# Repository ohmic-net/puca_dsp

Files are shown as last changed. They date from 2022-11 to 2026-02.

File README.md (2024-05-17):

# PÚCA DSP

**PÚCA DSP** is an open source, Arduino compatible ESP32 development board for audio and digital signal processing applications. In this repository you will find the hardware design files, and software examples for; 
- Arduino IDE
- VSCode/PlatformIO with Platform Espressif 32 and Framework arduinoespressif32 
- VSCode/PlatformIO with Platform Espressif 32 and Framework espidf
- ESP IDF

# Specifications 

**Processor & Memory**
- Espressif ESP32 Pico D4 Processor
- 32-bit dual core 80MHZ / 160MHZ / 240MHZ
- 4MB SPI Flash with 8MB additional PSRAM or 16MB External SPI Flash 
- Wireless 2.4GHz Wi-Fi -802.11b/g/n
- Bluetooth BLE 4.2
- 3D Antenna

**Audio**
- Wolfson WM8978 Stereo Audio Codec
- Audio Line In on stereo 3.5mm connector
- Audio Headphone / Line Out on stereo 3.5mm connector
- Stereo Aux Line In, Audio Mono Out routed to GPIO Header
- 2 x Knowles SPM0687LR5H-1 MEMS Microphones 
- ESD protection on all audio inputs and outputs
- Support for 8, 11.025, 12, 16, 22.05, 24, 32, 44.1 and 48kHz sample rates
- 1W Speaker Driver, routed to GPIO Header
- DAC SNR 98 dB, THD -84 dB (‘A’ weighted @ 48 kHz)
- ADC SNR 95 dB, THD -84 dB (‘A’ weighted @ 48 kHz)
- Line input impedance: 1 M ohm
- Line output impedance: 33 ohm

**Form Factor and Connectivity**
- Breadboard friendly
- 70mm x 24mm
- 11 x GPIO pins broken out to 2.54mm pitch header, with access to both ESP32 ADC channels, JTAG and capacitive touch pins
- USB 2.0 over USB Type C connector

**Power**
- 3.7/4.2v Lithium Polymer Rechargeable Battery, USB  or external 5V DC power source
- ESP32 and Audio Codec can be placed into low power modes under software control
- Battery voltage level detection
- ESD protection on USB data bus

# Documentation 
PUCA_DSP-PINOUT_V2

# Pin Description
pin_description_repo-2

# Absolute Maximum Ratings 
abs_max_repo_v2

Maximum voltage before clipping on Audio Input, Aux L & Aux R = 3.3V peak-to-peak, AC. Audio input paths are AC coupled. 

Maximum voltage on GPIO pins = 3.3V DC. GPIO pins are not overvoltage protected, for voltages higher than 3.3V use an input protection circuit such as a diode clamp or a level shifter.

# Current Consumption Characteristics 
current_repo

# Battery Voltage Monitoring
Battery voltage monitoring is available by soldering the BT_LVL solder jumper on the PCB top side, which routes the battery voltage to GPIO 14. 

# Physical Dimensions
phys_dimensions_repo

*Height measurement is with pin headers soldered. 

# Open Source Licensing 
certification-mark-IE000006-wide
**PÚCA DSP** is Open Source Hardware Association certified, and can be found on the OSHWA website here; https://certification.oshwa.org/list.html

Hardware design files are released as open source under the CERN v1.2 license. **PÚCA DSP** software examples are released under the MIT license, software examples using Faust DSP also contain additional license information relevant to Faust DSP. Please review these licenses before using these files in your own projects to understand your obligations.

# Video Tutorials
1. Getting started with VS Code and PlatformIO IDE - https://www.youtube.com/watch?v=hKllKXUncVo
2. Configuring the audio codec - https://www.youtube.com/watch?v=Auh9VE7Pjl8

# Need a board?
There are a few available on Tindie - https://www.tindie.com/products/ohmic/puca-dsp/

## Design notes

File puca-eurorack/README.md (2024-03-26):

# PÚCA Eurorack Module

This directory includes binary files (`firmware.bin`) for the Eurorack module. 

## Updating the firmware; 

On boot the module creates a WiFi soft access point with the network name "PÚCA DSP". If you open a browser window (Chrome, Firefox) and go to;`http://puca_dsp.local` you will find an html page with a firmware update function;

OTA_update

Select the new firmware.bin file to load from your local machine and click "Update". After the new firmware has been uploaded, the module will reset and the new firmware will boot. At this point the network connection will be lost, and then on reboot a new WiFi soft access point will be created. 

Note that you don't need to upload the partitions.bin or spiffs.bin files if using the web browser for over the air updates, unless you have changed these, they are included in each folder in case you are using esptool.py or the Espressif Flash Download Tool instead of the module OTA functionality.

## User Interface
User interface parameters and DSP parameters for each firmware are outlined below. On the module; 
- CV1 is the left CV input jack, CV2 is the middle CV input jack and/or the top potentiometer, and CV3 is the right CV input jack and/or the bottom potentiometer. 
- TRIG1 is the top trigger input and TRIG2 is the bottom trigger input. 
- TOUCH is the capacitive touch sensor activated by touching the PÚCA's paw. 

The `hardware_test_arduino` folder includes Arduino sketches for checking that the hardware functionality is working correctly.

## Current firmwares; 

- **SNES_Verb** - emulation of a SNES type reverb with a short delay line. CV2 is delay time, and CV3 is feedback. 
- **Oscillator** - a wavetable oscillator with 12 single cycle, band limited waveforms. CV1 is the 1V/Octave input, CV2 is the oscillator root frequency, and CV3 is linear FM. A TOUCH input or a trigger signal on TRIG1 will switch the waveform.
- **Chorus** - stereo chorus effect. CV2 is depth, and CV3 is phase difference. 

#### Notes on the oscillator frequency range; 

The 1V/Octave input has a range of 7 octaves, due to the non-linearity of the ESP32's ADC inputs the pitch tracking is accurate over 4 octaves and the lowest and highest octaves do not track accurately, as can be seen from the below graph whereby the linear response region is between 2V and 6V. The pitch resolution is 34.375mV per semitone or 0.34375 mV per cent. 

Puca_VOCT_input

The Oscillator root frequency range is from midi note A0 (27.50Hz) to A3 (220Hz), used in combination with the 1V/Octave input in practice this gives a musically usable range of around 4 to 6 octaves from A0 without note drift. 

The FM input allows for linear frequency modulation up to maximum frequency range of 1 midi note.

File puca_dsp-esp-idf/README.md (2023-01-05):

# ESP-IDF v5.0 Example

The examples in this directory build against [Espressif ESP-IDF development Framework v5.0](https://docs.espressif.com/projects/esp-idf/en/v5.0/esp32/get-started/index.html). Follow the documentation on the linked page to install v5.0 to build these examples.

If you are hoping to build against ESP-IDF v4.0, refer to the `puca_dsp-platformio-esp-idf` [examples](https://github.com/ohmic-net/puca_dsp/tree/main/puca_dsp-platformio-esp-idf).

To build, once the ESP-IDF toolchain is initialised (usually `get_idf`), run:
```
idf.py build
```
In this example's directory (`puca_dsp/puca_dsp-esp-idf`).

Two example I2S functions are provided in `main.cpp`:
- `passthrough()` sends all I2S data received from the ADC to the DAC, so that the PÚCA DSP is transparent.
- `sine_wave()` generates a 200Hz sine wave at the output.

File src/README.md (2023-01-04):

This directory is intended for project specific (private) libraries, and can be expanded over time to include 
different signal processing classes, networking and OTA functionality and user interface functionality.

Example directory structure; 

- Audio - contains audio codec driver (WM8978) and functions related to I2S audio configuration
- Control - contains functions related to control parameters (potentiometers, buttons, trigger inputs)

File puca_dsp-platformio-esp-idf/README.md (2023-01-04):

This directory contains software examples for; 
- VSCode/PlatformIO with Platform Espressif 32 and Framework esp-idf

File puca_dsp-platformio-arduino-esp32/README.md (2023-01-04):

This directory contains software examples for; 
- VSCode/PlatformIO with Platform Espressif 32 and Framework arduinoespressif32

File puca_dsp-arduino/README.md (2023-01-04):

This directory contains software examples for; 
- Arduino IDE

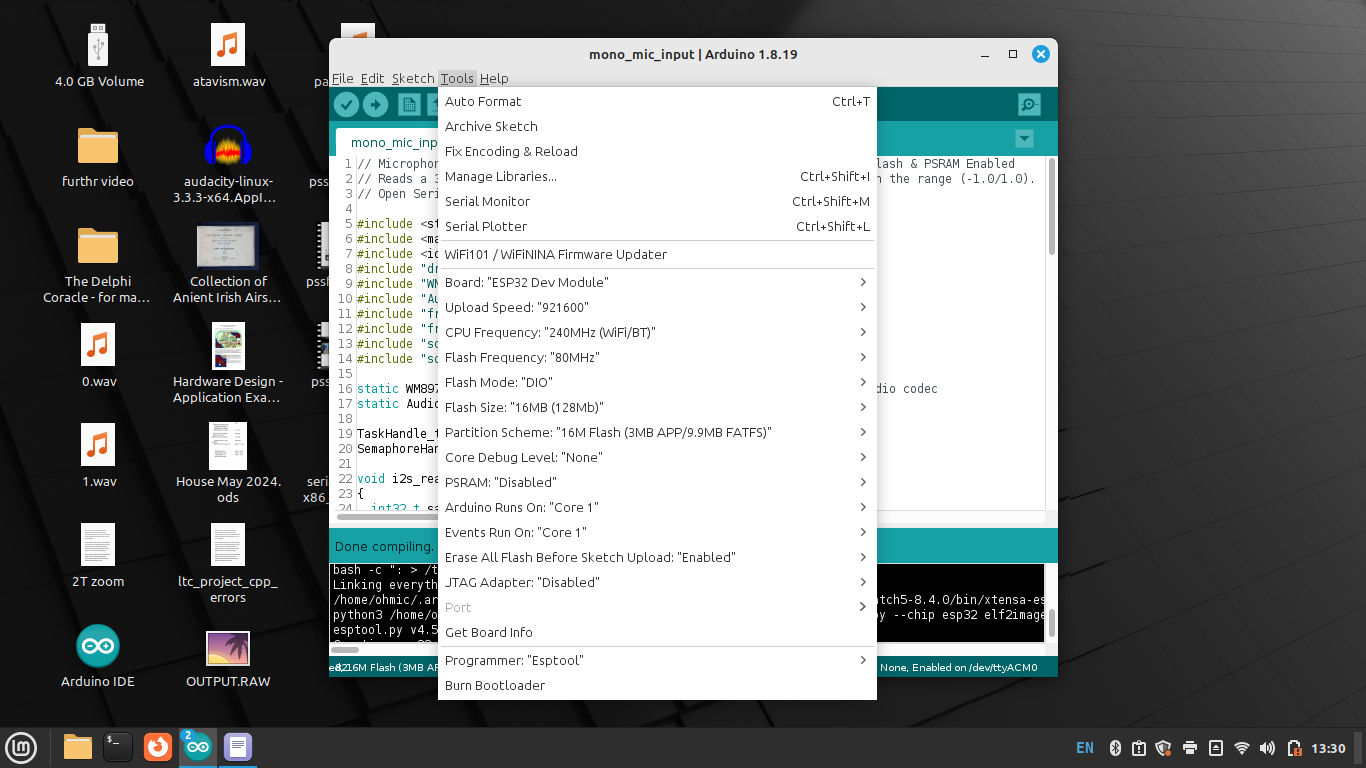
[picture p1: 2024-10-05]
puca_dsp-arduino/strawberry edition/Arduino_IDE_settings.png

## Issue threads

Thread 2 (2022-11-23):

https and mp3

nebulos13, 2022-11-23:
hello i try webradio in arduino -internet-radio.ino with this list radio:

https://radiobonheur.ice.infomaniak.ch/radiobonheur-128-1.mp3
http://direct.franceinter.fr/live/franceinter-midfi.mp3
https://ais-live.cloud-services.paris:8443/rfm.mp3
http://cdn.nrjaudio.fm/audio1/fr/30401/mp3_128.mp3?origine=fluxradios
http://radioclassique.ice.infomaniak.ch/radioclassique-high.mp3
http://radio8.pro-fhi.net:9005/atlantis320
http://tachyon.shoutca.st:8084/live
http://stream.levillage.org/canalb?1362308951917.mp3

but nothing playing just http://direct.franceinter.fr/live/franceinter-midfi.mp3
how to have mp3 extention and https
thanks to your answer

nebulos13, 2022-11-23:
now my problem is the button to change mp3 flux

g0fcu, 2022-11-24:
There is a difference in code between the Arduino IDE and VSCode IDE versions. The Arduino version has the set up of the interrupt which triggers when the button is pressed. However, for me this version continuously reboots. The VSCode has these lines (123-127) commented out so the station which plays is that which station_select is set to in Setup(). Uncommenting these lines causes the same constant reboots as in the Arduino version.

nebulos13, 2022-11-24:
Thanks to your answer. Have you solution to use button to change radio station ?

g0fcu, 2022-11-25:
I just cloned the git repository again and my previous comment about code differences is wrong (I must have made the change). The button and the interrupt task is not initialised as the code is commented out, un-commenting it causes the device to continuously reboot. I don't know why.

nebulos13, 2022-12-04:
voici le modèle 3D du boitier , here is the 3D model of the box:: [https://www.nebulose.fr/modele3d.zip](url)

pour le bouton c'est quoi le code pour changer de radio?
for the button what is the code to change the radio?

nebulos13, 2022-12-06:
thanks but i use arduino IDE : /main/puca_dsp-arduino/Original%20Edition/arduino-internet_radio)/arduino-internet_radio.ino

nebulos13, 2022-12-08:
Hello in visual studio code i have this error when i build projet webradio: pio\build\tinypico\lib103\STM32duino_STM32Ethernet\EthernetServer.cpp.o] Error 1

andy-wi, 2023-01-09:
hi @nebulos13 I'm not sure you have the correct toolchain set up for your project.... the STM32duino libraries are not required for this project and EthernetServer.cpp is not a dependency of this example. Did you install PlatformIO and ESP-IDF as extensions in VS code and could you post your platform.ini file?

andy-wi, 2023-01-09:
When your build starts in VS Code, what platform and packages are installed, e.g;

```
PLATFORM: Espressif 32 (3.0.0) > TinyPICO
HARDWARE: ESP32 240MHz, 320KB RAM, 4MB Flash
DEBUG: Current (esp-prog) External (esp-prog, iot-bus-jtag, jlink, minimodule, olimex-arm-usb-ocd, olimex-arm-usb-ocd-h, olimex-arm-usb-tiny-h, olimex-jtag-tiny, tumpa)
PACKAGES:
 - framework-arduinoespressif32 @ 3.10004.210126 (1.0.4)
 - tool-esptoolpy @ 1.30000.201119 (3.0.0)
 - toolchain-xtensa32 @ 2.50200.97 (5.2.0)
```

nebulos13, 2023-11-01:
it's ok with the button  !

platformio.ini
-->
[env:tinypico]
platform = espressif32@3.0.0
board = tinypico
framework = arduino
lib_extra_dirs = ~/Documents/Arduino/libraries
board_build.f_cpu = 240000000L
board_build.flash_size = 4MB
board_build.partitions = min_spiffs.csv
board_build.flash_mode = dio
; Serial Monitor options
monitor_speed = 115200

upload_port = COM3
build_type = release
build_flags =
    ;-DLOG_LOCAL_LEVEL=ESP_LOG_DEBUG
    ;-DBOARD_HAS_PSRAM
    ;-mfix-esp32-psram-cache-issue
    ;-DCORE_DEBUG_LEVEL=5

and

add  //conf.clk_flags = 0; ligne in WM8978.cpp ligne 57

nebulos13, 2023-11-01:
thanks

nebulos13, 2023-11-01:
;-)

Closed 2023-12-21.

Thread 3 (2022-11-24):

Internet Radio example fails

g0fcu, 2022-11-24:
Tested on both Arduino IDE and VSCode/PlatformIO with Platform Espressif 32 and Framework arduinoespressif32.

In both cases the serial output is as below. It seems to not be getting out of the Setup section and resetting.
`
rst:0x5 (DEEPSLEEP_RESET),boot:0x13 (SPI_FAST_FLASH_BOOT)
configsip: 188777542, SPIWP:0xee
clk_drv:0x00,q_drv:0x00,d_drv:0x00,cs0_drv:0x00,hd_drv:0x00,wp_drv:0x00
mode:DIO, clock div:1
load:0x3fff0018,len:4
load:0x3fff001c,len:1216
ho 0 tail 12 room 4
load:0x40078000,len:10944
load:0x40080400,len:6388
entry 0x400806b4
Setup
WiFi connected
info        info        info        info        info        streaminfo  Connect to listen2.ntslive.co.uk on port 80, extension /listen.pls
ets Jun  8 2016 00:22:57

rst:0x5 (DEEPSLEEP_RESET),boot:0x13 (SPI_FAST_FLASH_BOOT)
configsip: 188777542, SPIWP:0xee
clk_drv:0x00,q_drv:0x00,d_drv:0x00,cs0_drv:0x00,hd_drv:0x00,wp_drv:0x00
mode:DIO, clock div:1
load:0x3fff0018,len:4
load:0x3fff001c,len:1216
ho 0 tail 12 room 4
load:0x40078000,len:10944
load:0x40080400,len:6388
entry 0x400806b4
Setup
WiFi connected
info        info        info        info        streaminfo  Connect to dublindigitalradio.out.airtime.pro on port 8000, extension /dublindigitalradio_a
ets Jun  8 2016 00:22:57

rst:0x5 (DEEPSLEEP_RESET),boot:0x13 (SPI_FAST_FLASH_BOOT)
configsip: 188777542, SPIWP:0xee
clk_drv:0x00,q_drv:0x00,d_drv:0x00,cs0_drv:0x00,hd_drv:0x00,wp_drv:0x00
mode:DIO, clock div:1
load:0x3fff0018,len:4
load:0x3fff001c,len:1216
ho 0 tail 12 room 4
load:0x40078000,len:10944
load:0x40080400,len:6388
entry 0x400806b4
Setup
WiFi connected
info        info        info        info        streaminfo  Connect to streamer.dgen.net on port 8000, extension /rinseradio
ets Jun  8 2016 00:22:57
`

g0fcu, 2022-11-24:
User error!

Closed 2022-11-24.

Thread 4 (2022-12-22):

esp-idf Example fails to build / is not documented

davidswarbrick, 2022-12-22:
Attempting to compile the `esp-idf_puca_dsp_setup` example after following the ESP-idf [installation instructions](https://docs.espressif.com/projects/esp-idf/en/latest/esp32/get-started/linux-macos-setup.html) (running on the master branch)
```
idf.py build
...
[849/851] Linking CXX executable esp32_picodsp_setup.elfFAILED: esp32_picodsp_setup.elf .c.obj
...
/home/david/.espressif/tools/xtensa-esp32-elf/esp-2022r1-11.2.0/xtensa-esp32-elf/bin/../lib/gcc/xtensa-esp32-elf/11.2.0/../../../../xtensa-esp32-elf/bin/ld: esp-idf/freertos/libfreertos.a(app_startup.c.obj):(.literal.main_task+0x28): undefined reference to `app_main'
/home/david/.espressif/tools/xtensa-esp32-elf/esp-2022r1-11.2.0/xtensa-esp32-elf/bin/../lib/gcc/xtensa-esp32-elf/11.2.0/../../../../xtensa-esp32-elf/bin/ld: esp-idf/freertos/libfreertos.a(app_startup.c.obj): in function `main_task':
/home/david/esp/esp-idf/components/freertos/app_startup.c:206: undefined reference to `app_main'
collect2: error: ld returned 1 exit status
ninja: build stopped: subcommand failed.
ninja failed with exit code 1
```

My understanding is that the `extern` definition in `main.cpp` should be sufficient to define `app_main`, thus I'm unsure if:

- I've misconfigured my project, e.g. running against the wrong version of `esp-idf` - if so I'd be happy to address this and add a README with instructions.
- Or, I've found a bug in this example, e.g. a configuration of CMAKE variables to ensure our desired `app_main` is linked.

Please do let me know of any pointers to help address this (I'm reasonably new to ninja/CMAKE/etc. so will update when/if I learn any more details)

davidswarbrick, 2022-12-22:
I see this example may have been created with the [esp32 Faust tutorial](https://faustdoc.grame.fr/tutorials/esp32/).

davidswarbrick, 2022-12-28:
This issue stems from the rename in the v5.0 stable branch of the esp-idf from `src` to `main`. Following the guidance from the docs [here](https://docs.espressif.com/projects/esp-idf/en/stable/esp32/api-guides/build-system.html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) you can adjust this by adding `set(EXTRA_COMPONENT_DIRS src)` to line 2 of `CMakeLists.txt` in the root directory.

The example still fails to build as the i2s/i2c header files have changed. I'll continue to debug and submit a PR for the new version. If you find this thread, please attempt with v4 of the esp-idf.

Closed 2022-12-30.

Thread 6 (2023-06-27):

Example code for using 2 mics simultaneously and streaming it in real time over network while saving the stream locally to a USB flash disc

dumblob, 2023-06-27:
I wonder if anyone tried what the topic describes?

Any hints how to go about it (especially the "parallel" nature of it with real-time guarantees).

andy-wi, 2023-07-13:
One possible approach could be;

1. Modify this code for the 2 microphones, currently it uses one (mono) input - https://github.com/ohmic-net/puca_dsp/tree/main/puca_dsp-platformio-arduino-esp32/original%20edition/arduino-esp32_mono_mic_input you might want one interleaved array for stereo rather than 2 separate arrays for left and right signals.
2. Write the output to a ringbuffer, then, when the ringbuffer is full read from it to the write buffer for the flash memory, and to the buffer for the network stream. Possibly you could use 2 ringbuffers, the ringbuffer for the network stream may need to be larger size depending on the network latency?

I've used this approach for writing to SPIFFS or SD card for real time recording, but not at the same time / in parallel with network streaming. I don't think from a hardware perspective that the USB port on puca_dsp can be configured as a USB flash disc also, you might need to write a UART to USB memory stick drive / bridge using another one of the UART ports on the ESP32.

dumblob, 2023-07-13:
Thanks for the pointers - sounds kind of doable. Btw. the interleaved array is an interesting idea. Never saw that before :wink:.

Now I will need to think about how to encrypt the network stream to hide the content, how to (re-)authenticate the downloading site (without stream interruption), etc.

Closed 2023-10-31.

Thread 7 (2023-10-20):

Not an issue: Puca DSP support added to WLED-MoonModules!

troyhacks, 2023-10-20:
WM8978 support for WLED AudioReactive has been on my to-do list for well over a year - and getting a few Puca DSP boards yesterday pushed me to finally do it:

https://github.com/MoonModules/WLED/pull/84

This should be merged in shortly, and I would expect it'll be accepted up to WLED "mainstream" in due time.

Currently it's set to do line-in with loopback/passthru to line-out, but I may eventually create a separate config for microphone input. I'm mostly working on line-in for audio reactive work as microphones aren't the ideal solution for accuracy in loud environments like DJ events, live performances, etc.

This is a great board, thanks for developing it! A huge improvement over the LyraT I've been targeting (and also added to WLED!)

 My working tree is here if anyone wants to try it sooner: https://github.com/troyhacks/WLED/tree/WM8978

andy-wi, 2023-10-31:
Thanks @troyhacks for adding the WM8978 support to WLED AudioReactive!

And also for the feedback on the PUCA DSP board, there are no documented hardware issues with it as far as I'm aware and it was fully tested during development, if you come across anything though please open an issue here as may be useful for other developers.

Closed 2023-10-31.

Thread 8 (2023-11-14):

WM8978 and disabling onboard microphones

troyhacks, 2023-11-14:
I've been having issues trying to completely disable the microphone path on the Puca DSP board.

Generally, I will say that line-in is a much stronger signal and the mic contamination isn't high - but during line-in silence the code we use  in WLED will eventually auto-gain and find a mic signal in the background.

My WM8978 init code and comments are here:

https://github.com/troyhacks/WLED/blob/5fa8cd0a293847d3b5e8d6b37623d471accebd01/usermods/audioreactive/audio_source.h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

I feel like I've been back and forth on the WM8978 spec sheet and set everything on or off I can think of - but if you have any hints, I'd love to hear them.

(It also doesn't help that I use this board in very loud rave-type environments, so the sound pressure is pretty high in the room. 🤣)

Thanks!

andy-wi, 2023-11-21:
I've used this function in the library from this repository to disable or enable the mic inputs -  `wm8978.inputCfg(1,0,0);` which does give a definite "off",  but I've only tested in normal room and not loud gig type environments.

Is your function ` _wm8978I2cWrite(44,0b000000000); // Disconnect microphones` definitely writing to the same register (looks to be), but is it actually writing the correct values... I found I had to read the default value of the registers first, then write back using bitwise operations, and then (optionally) read again to check the value matches what the desired datasheet value should be.

Might be relevant - https://electronics.stackexchange.com/questions/640531/why-is-a-register-initialised-through-bitwise-operations-instead-of-a-binary-str

troyhacks, 2023-11-27:
>but is it actually writing the correct values... I found I had to read the default value of the registers first, then write back using bitwise operations, and then (optionally) read again to check the value matches what the desired datasheet value should be.

Well, good question...!

As far as I know, the WM8978 has no way to query the registry over I2C. The common flow in the libraries seems to be:

1. Read default/current registry value from WM8978_REGVAL_TBL
2. Do something to manipulate the value in a function
3. Call writeReg() which:
4. Writes the value to the I2C bus
5. ...and...
6. Updates the value in WM8978_REGVAL_TBL as we can't read it from the chip

So I guess the question is more "am I doing manually what the (hopefully known-working) library is doing?"

`wm8978.init();
wm8978.inputCfg(0,1,0);`

2 = 0b110110000
44 = 0b000000000 # yup, correct
47 = 0b101010000
48 = 0b101010000
47 = 0b101010000
48 = 0b101010000

...so I think more verification work is needed on my end.

I'll take the library and see if I can make it config in a way that works, and then test my code against a dump of the registry array and see if just sending all the final values is enough, or if I need to initialize it in a particular sequence.

Will report back. Thanks!

troyhacks, 2024-02-06:
I've done some additional testing and I have it working much more reliably, but not entirely fixed.

The leakage from the microphones seems with be within the WM8978 chip itself - if I mute L2 and R2 then the issue goes away - so it's clearly something within that signal path, which should NOT be the microphone path, but they're kinda adjacent.

The biggest help seems to be in registry 1. The bit for microphone bias enable - "MICBEN"  - seems to like being turned on. Secondly, there's a bit for BUFIOEN which is a tie-off for unused IO pins - this should also be enabled. Finally, setting the VMIDSEL to 300kΩ seems to help as well.

`_wm8978I2cWrite( 1,0b000111110);`

Overall , the issue does not go away entirely - but the microphones don't seem to leak nearly as badly. WLED has its own AGC for I2S samples, so this can still auto-range and hear "something" - but that is lessened greatly, and the WLED AGC seems to squelch it out eventually.

I'm curious if the AUXR/AUXL paths have the same issues, but I picked this board for the 1/8" inputs and outputs so I'm not likely to bother now that it's not reacting to loud noises in the room (or not as much). 😄

Thanks again for an amazing piece of hardware - it's been a great companion for WLED!

andy-wi, 2024-02-12:
Great, good to hear! The datasheet for WM8968 doesn't contain any values for ADC input path crosstalk between the channels, however, the datasheet for WM8962B which is a similar codec has a section on this, where;

> The ADC path is enabled from one input pin; -6dBV test signal applied to the other input; crosstalk measured at ADC output. The test is repeated with the two input pins swapped; the crosstalk figure is the worst case of the two measurements.

Test values are given in a table for 1kHz and 10kHz for different input paths, such as;

> IN2 / IN4 ADC input path crosstalk 1kHz -90 dB, 10kHz -69dB

There looks to be an difference of around -20dB between the 1kHz and 10kHz values. The WM8978 _may_ have similar values to these, with increased ADC input path crosstalk at higher frequencies?

Do you have the input PGAs enabled or disabled? (register 2) You could try disabling these also. The AUXL/AUXR input paths are post the input PGA before the ADC, if there is a difference with either the PGA disabled or using the AUX inputs then possibly some of the crosstalk could be in the PGA.

troyhacks, 2024-02-16:
As far as I know, the PGA is disabled and also muted - medium confidence here, but I have spent a fair amount of time testing.

When I mute L1 and R1 then the microphone effect disappears - so that would seem to indicate.... something crosstalky?

My experiments at least confirmed it seems I'm hearing the microphones in the wrong place, and adjusting the regular microphone path has no effect on this issue.

At this point I don't have a significant issue and  I have found at least somewhat of a workaround, so I'm content and educated. 👍🏻

Thank you!

Closed 2024-03-26.

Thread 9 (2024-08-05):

Question rather than issue: Is there some JTAG documentation somewhere?

AndrewCapon, 2024-08-05:
Hi Guys,

I want to use the USB port as a midi device so I need to get JTAG debugging going over the pins.

Is there any documentation anyway about how to do this, pins to use, fuses to burn etc?

Many thanks

Andy

AndrewCapon, 2024-08-07:
Actually is it even possible to use the USB at all or is it just power and the serial port?

andy-wi, 2024-12-16:
This issue was answered in email conversation at the time of posting. Just adding here as well;

Yes the JTAG pins are available; see the ESP32-PICO-D4 datasheet for details on JTAG debugging.

The USB is just power/charging and serial communication (as per schematics).

Closed 2024-12-16.

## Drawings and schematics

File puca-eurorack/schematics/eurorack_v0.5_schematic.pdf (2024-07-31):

## Audio Inputs

## Power

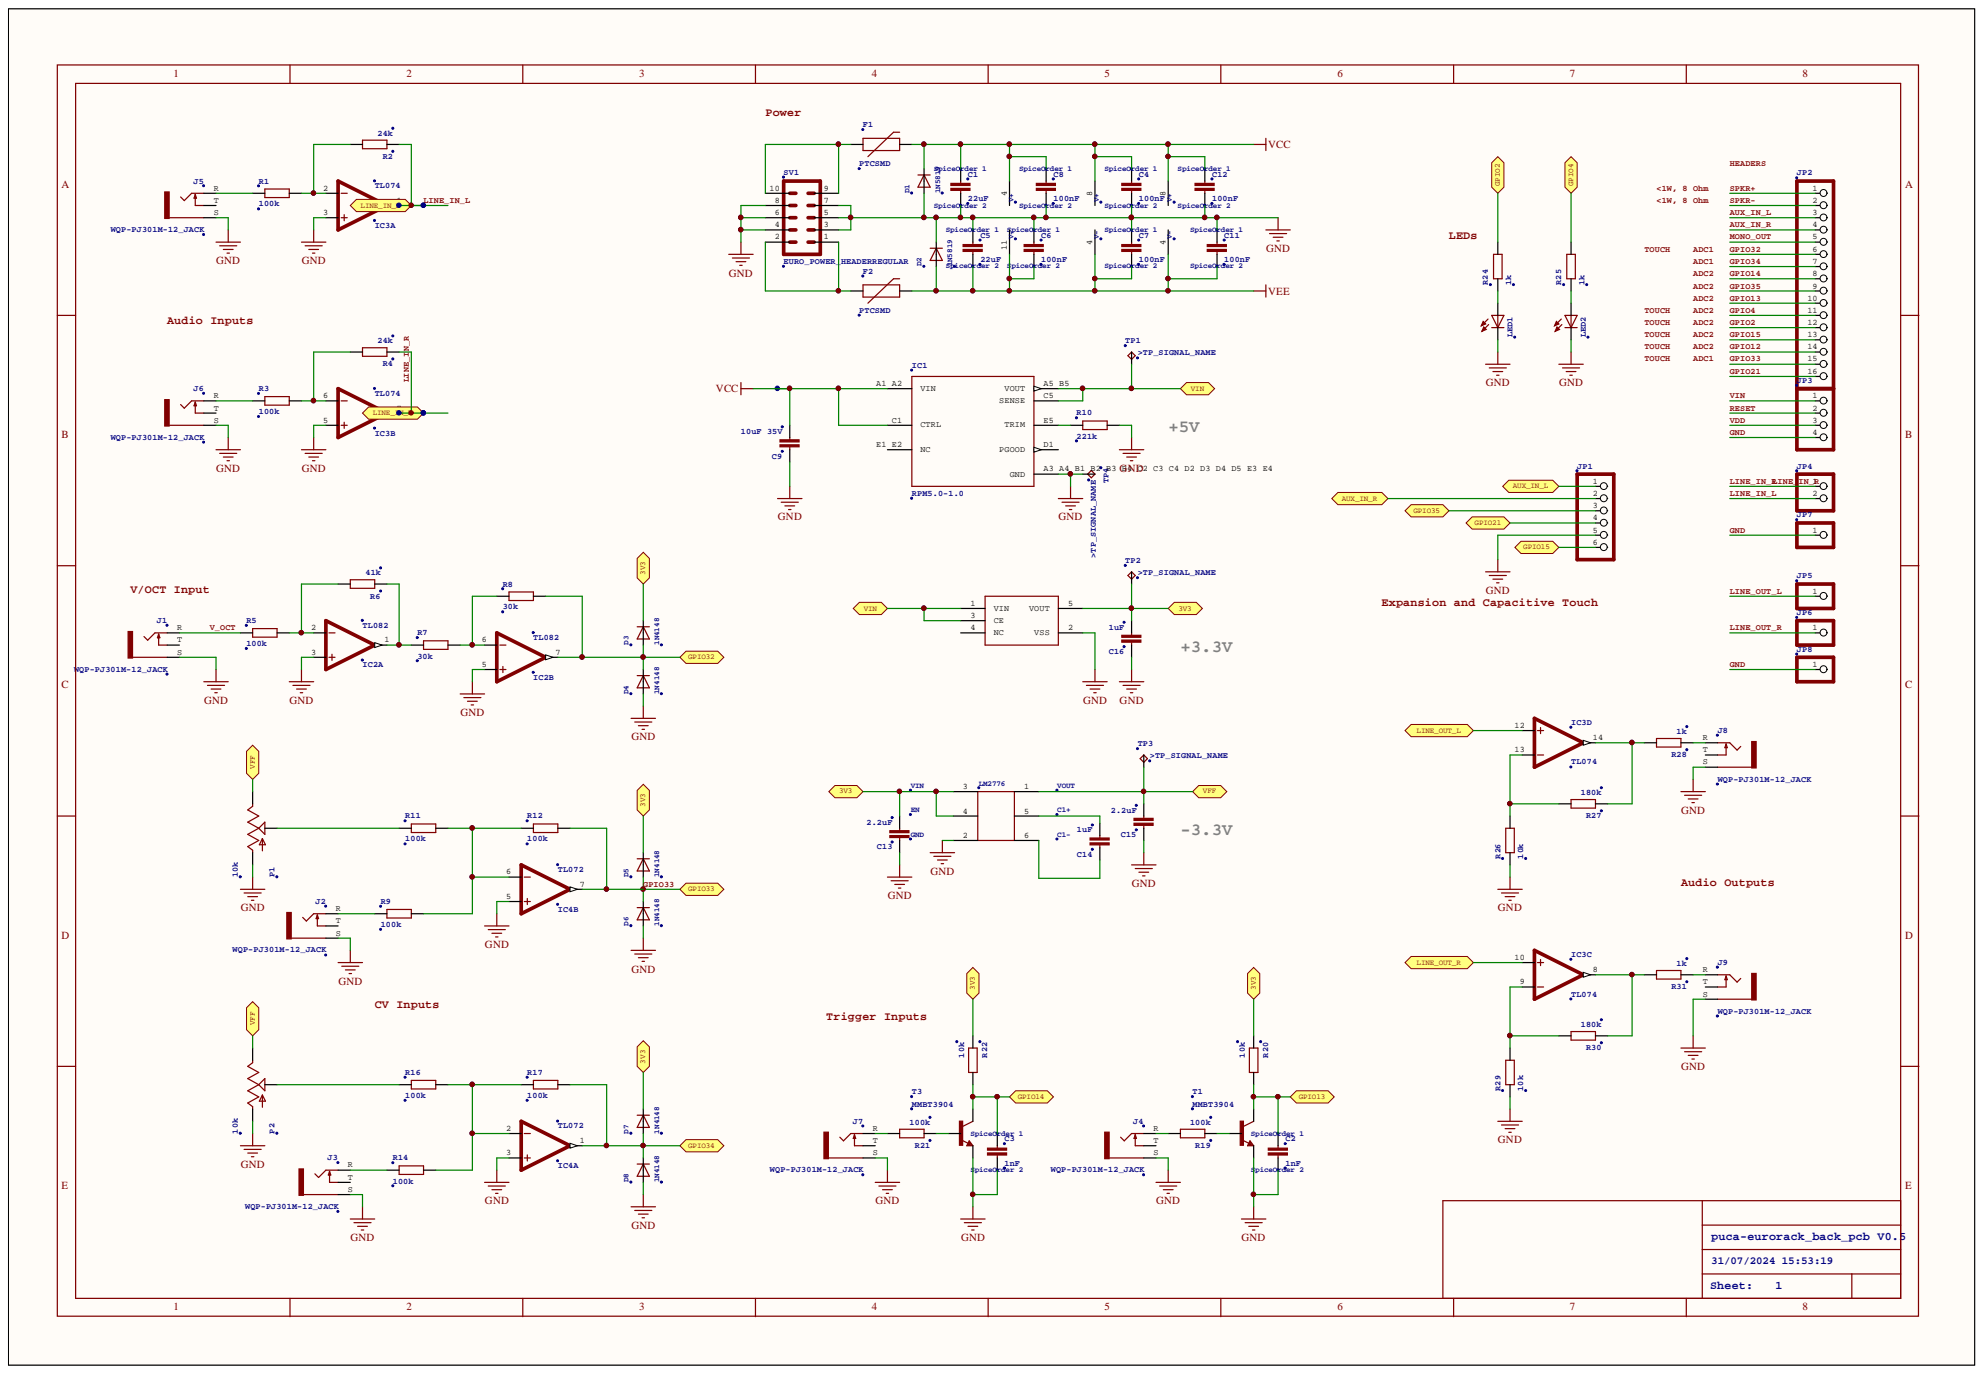
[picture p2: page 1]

Expansion and Capacitive Touch

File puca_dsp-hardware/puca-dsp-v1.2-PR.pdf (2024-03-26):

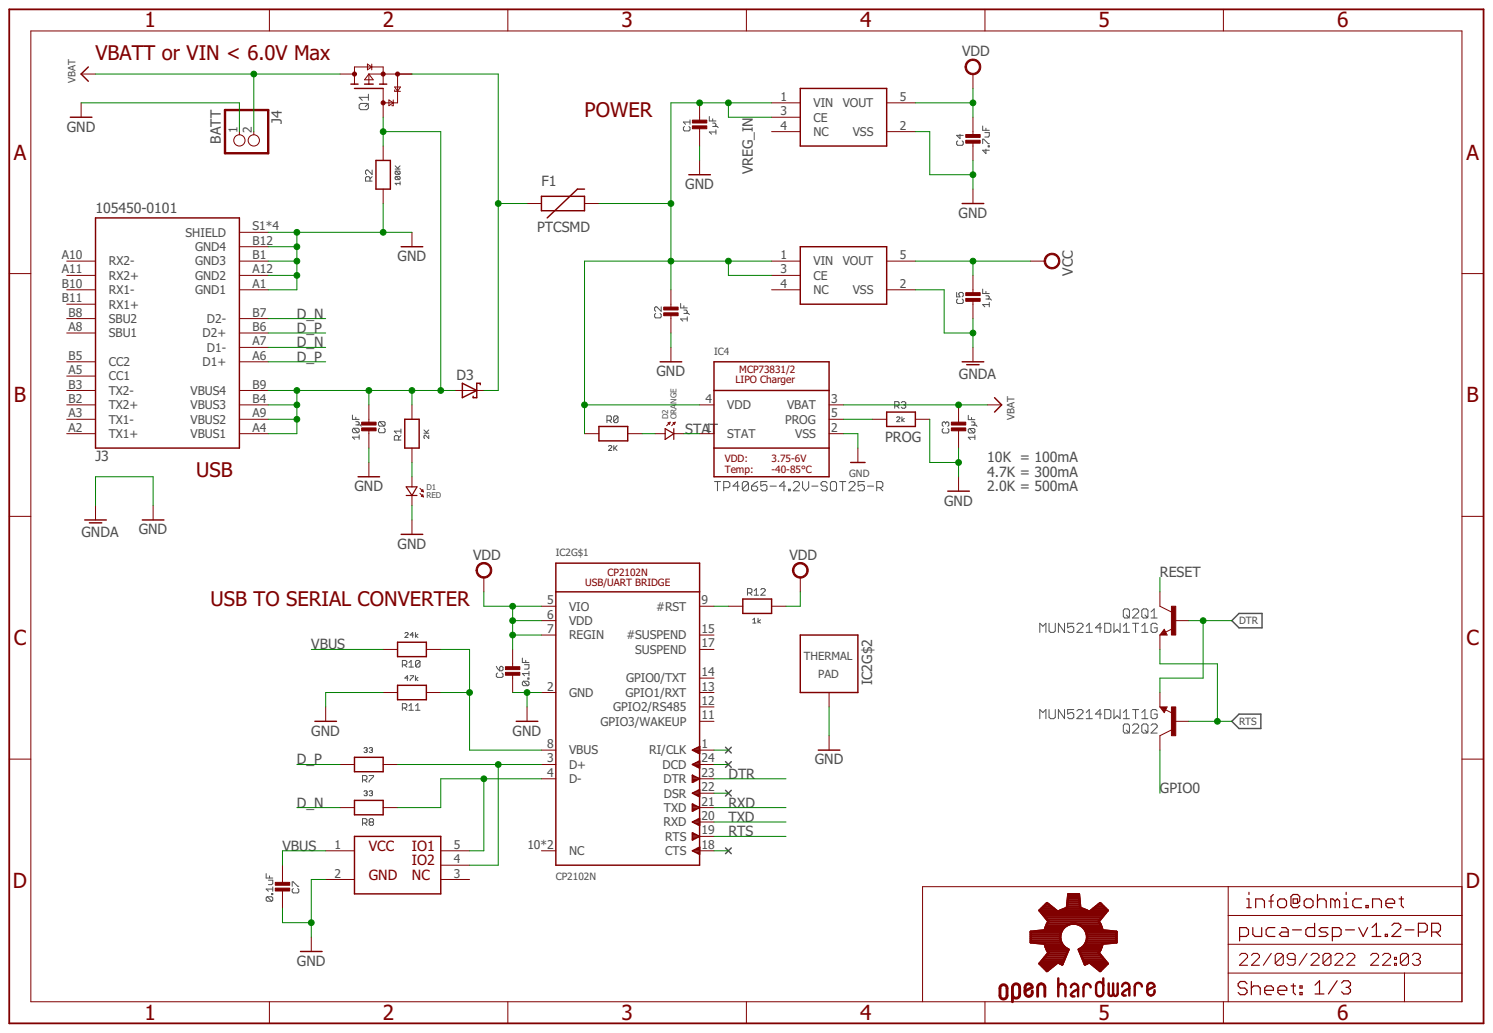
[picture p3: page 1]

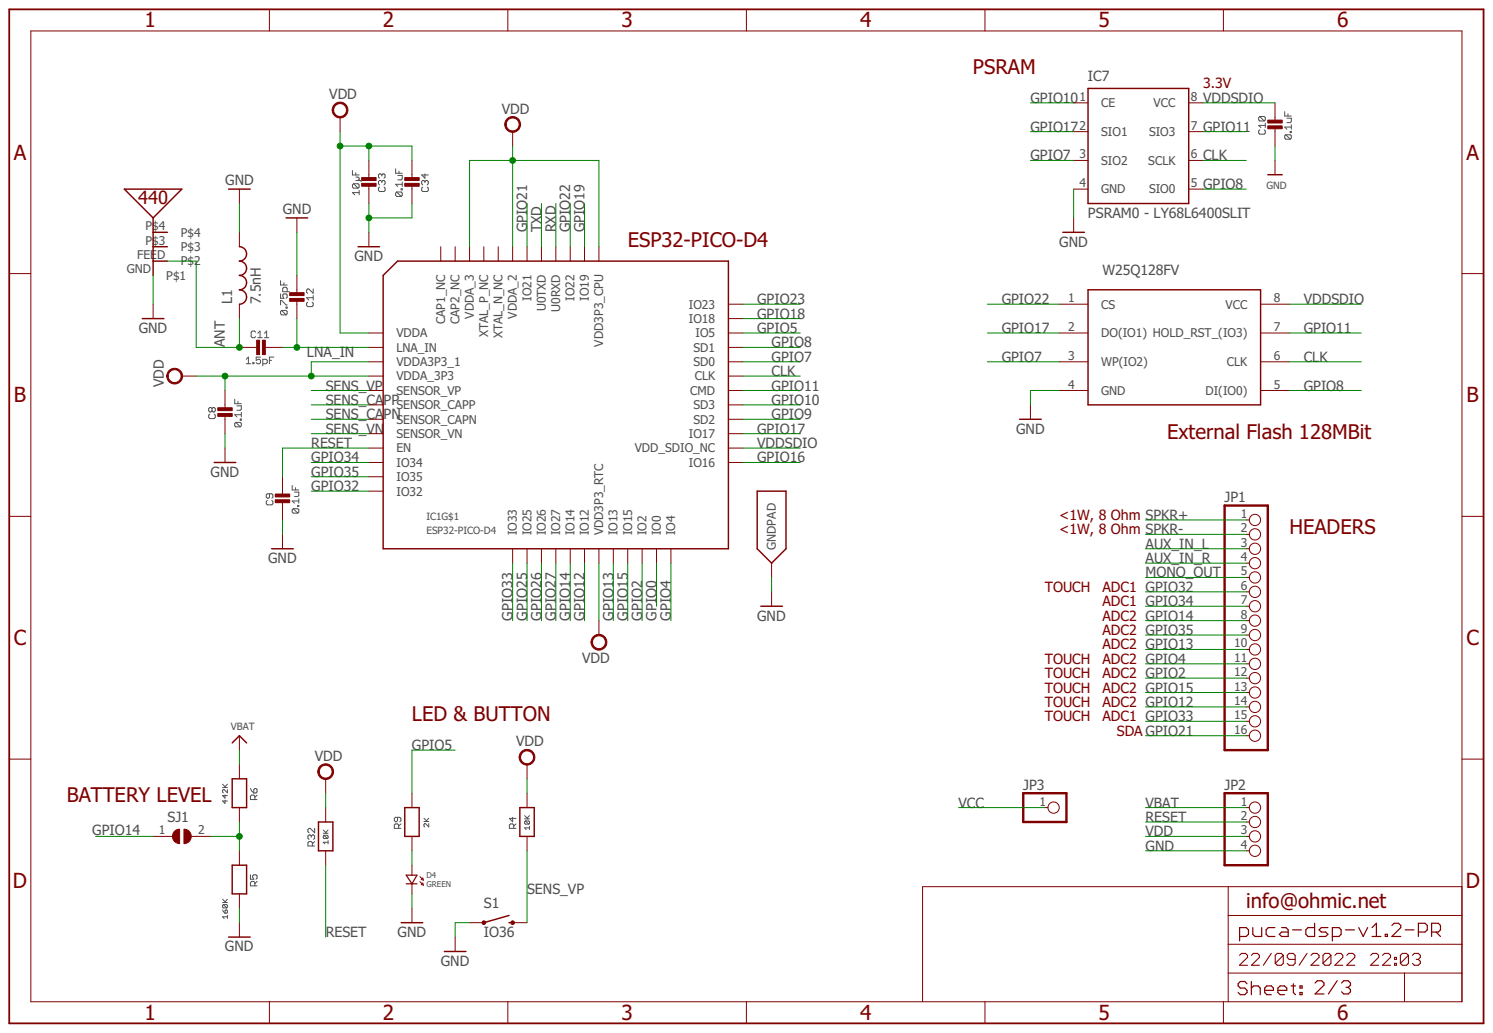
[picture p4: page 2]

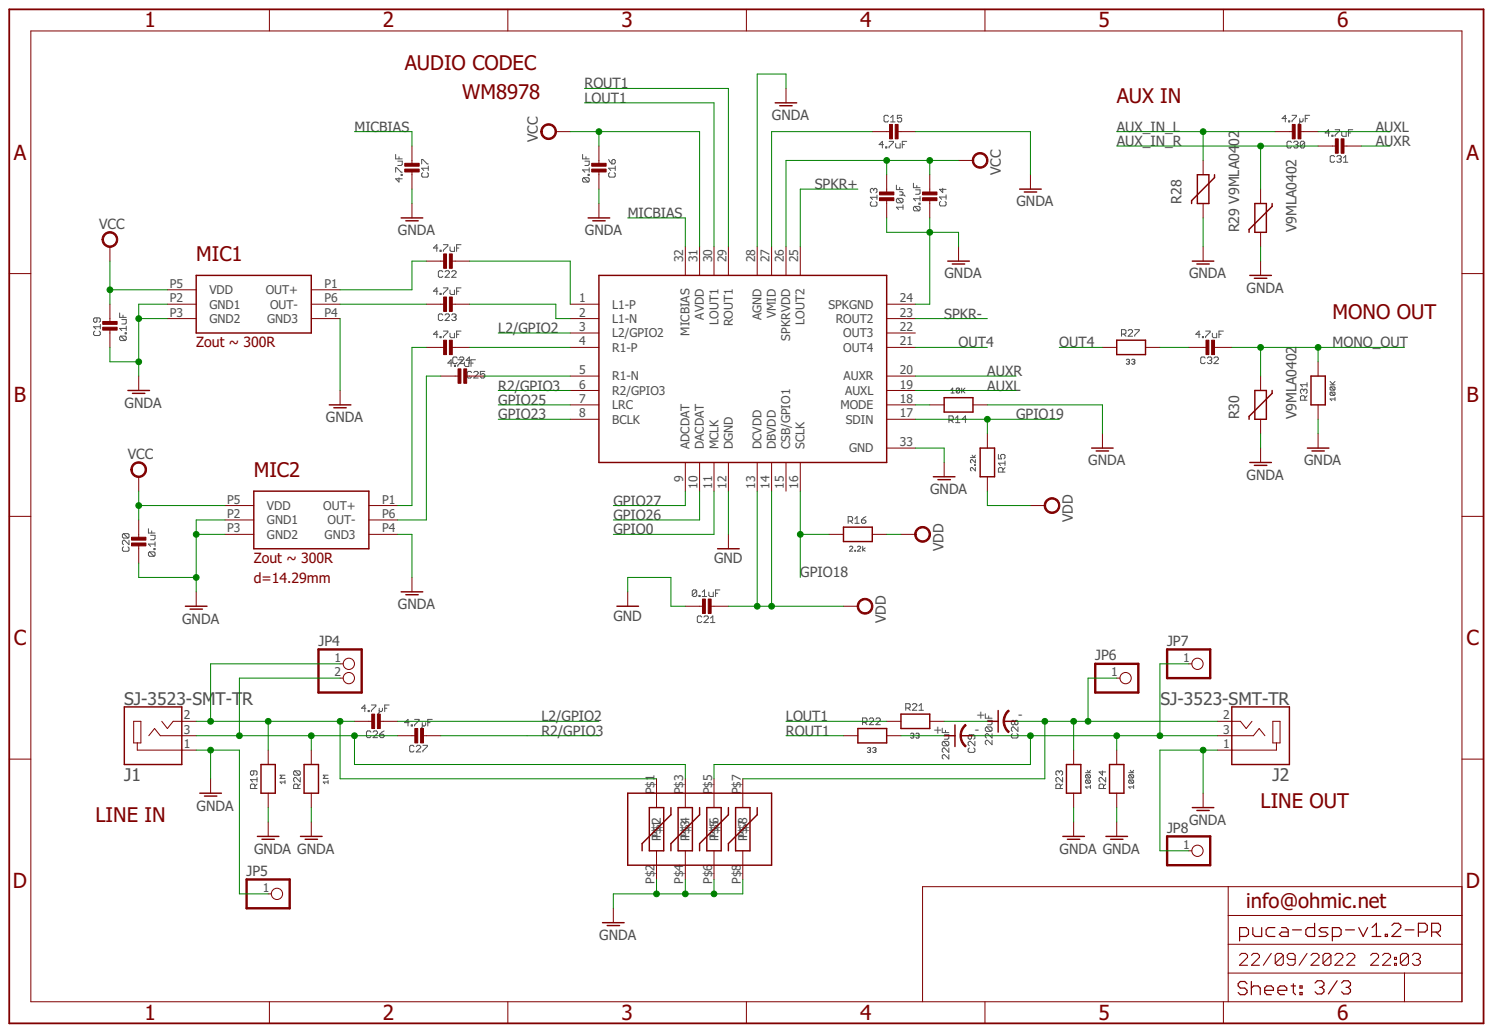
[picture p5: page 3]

AUDIO CODEC

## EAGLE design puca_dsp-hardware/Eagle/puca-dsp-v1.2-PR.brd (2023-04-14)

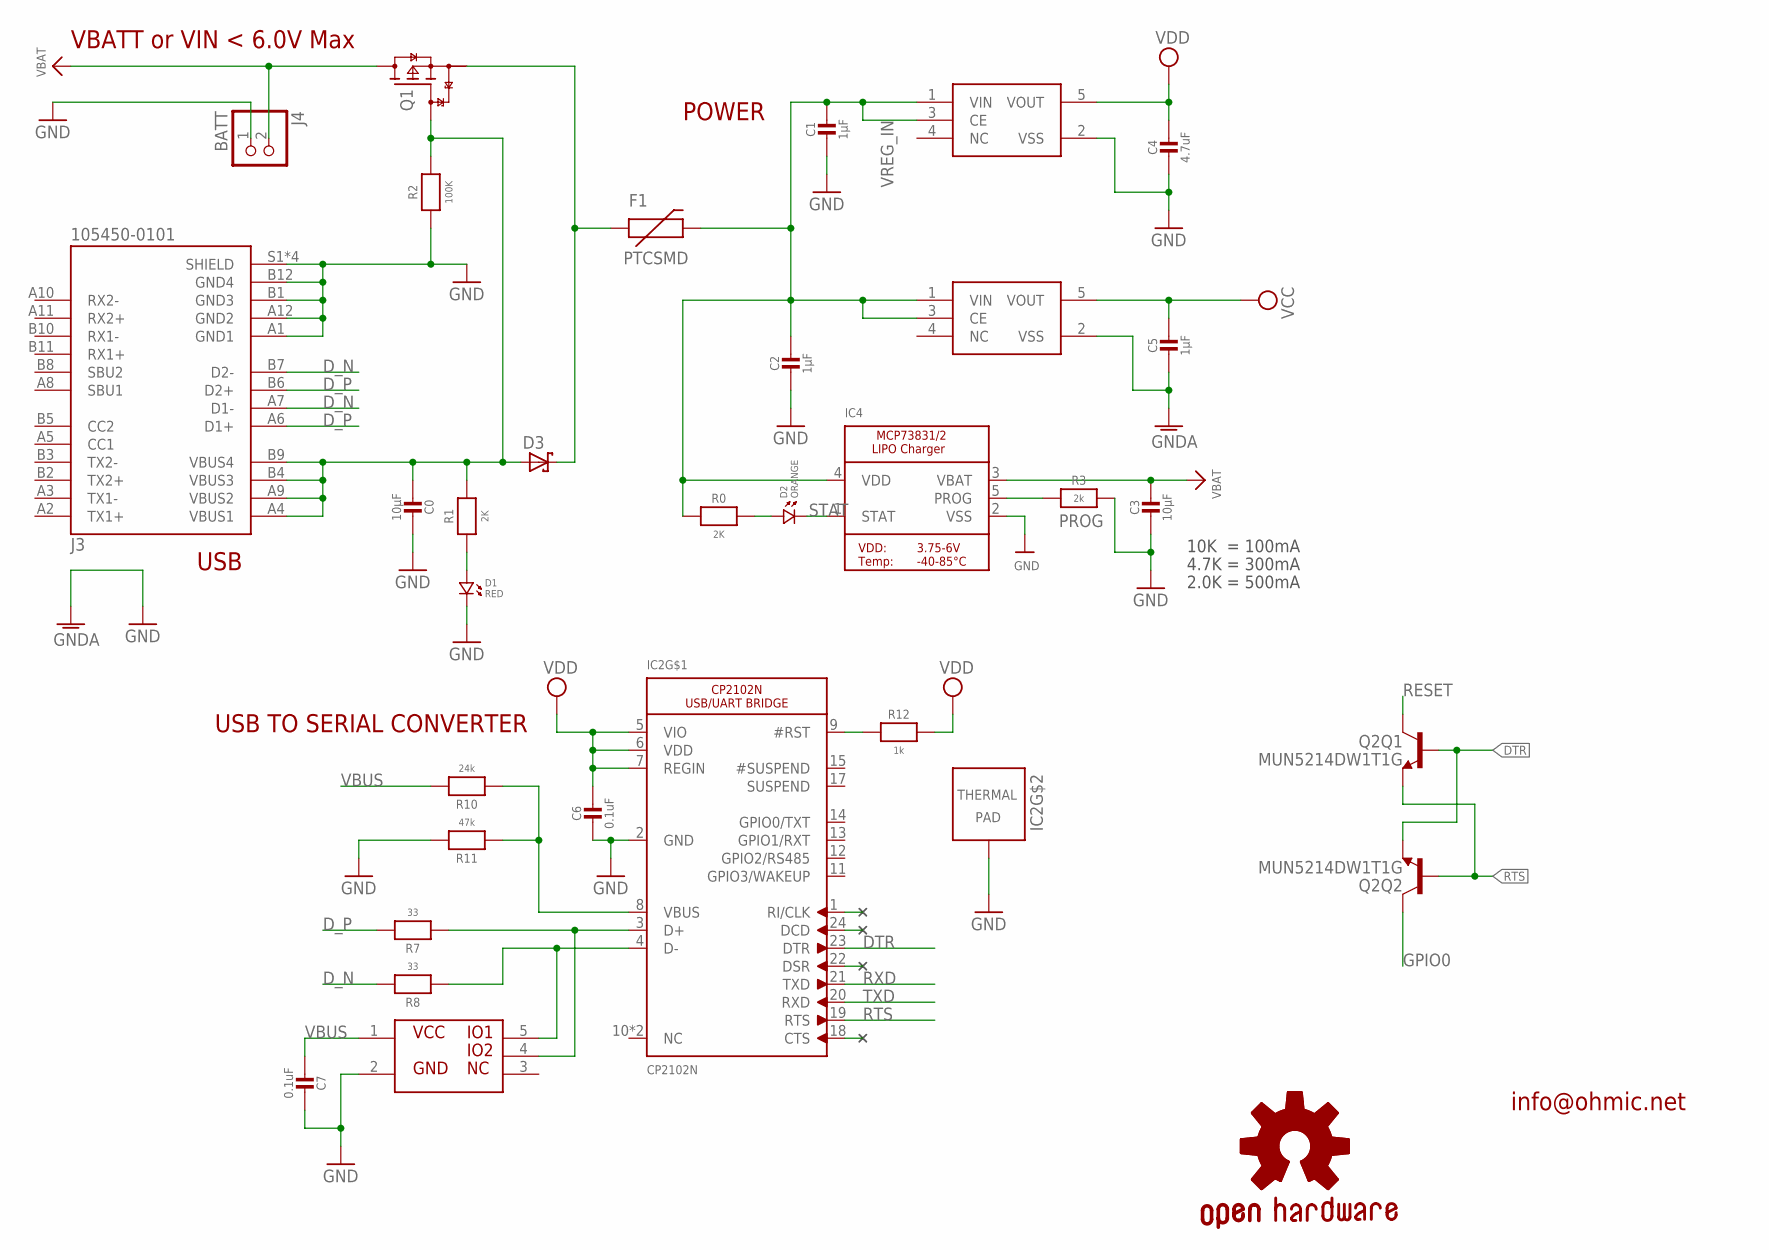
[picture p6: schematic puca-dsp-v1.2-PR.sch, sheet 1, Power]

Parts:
C0, C3: 10µF; _0603MP
C1, C2, C5: 1µF; _0402MP
C4: 4.7uF; _0402MP
C6, C7: 0.1uF; _0402MP
D1: RED; 0402.LED
D2: ORANGE; 0402.LED
D3: BAT60J; SOD323_ST
F1: PTCSMD; PTC-1206
GOLD_ORB_SM1: OSHWLOGO_GOLD_ORB_SM; OSHW2
IC2: CP2102N; MICROBUILDER_QFN24_4MM_SMSC
IC4: TP4065-4.2V-SOT25-R; SOT23-5
IC5, IC6: XC6210; SOT95P285X145-5N
IC8: NUP2114UPXV5T1G; SOT50P160X60-5N
J3: 105450-0101; MOLEX_105450-0101
J4: BATT; JST-PH-2-THM
Q1: SSM3J56ACT; SOT883(B)
Q2: MUN5214DW1T1G; DUAL_NPN_SC70-6
R0, R1: 2K; _0402MP
R2: 100K; _0402MP
R3: 2k; _0402MP
R7, R8: 33; _0402MP
R10: 24k; _0402MP
R11: 47k; _0402MP
R12: 1k; _0402MP

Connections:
D1_N: IC2.4 (D-), IC8.5, R8.1
D1_P: IC2.3 (D+), IC8.4, R7.1
DTR: IC2.23 (DTR), Q2.1 (E), Q2.5 (B)
D_N: J3.A7 (D1-), J3.B7 (D2-), R8.2
D_P: J3.A6 (D1+), J3.B6 (D2+), R7.2
GND: C0.1, C1.2, C2.2, C3.2, C4.2, C6.2, C7.1, D1.P$2 (2), IC2.2 (GND), IC2.THERM (TP), IC4.2 (VSS), IC5.2 (VSS), IC8.2, J3.A1 (GND1), J3.A12 (GND2), J3.B1 (GND3), J3.B12 (GND4), J3.S1 (SHIELD), J3.S2 (SHIELD), J3.S3 (SHIELD), J3.S4 (SHIELD), J4.1, R2.2, R3.2, R11.2; also elsewhere on the board
GNDA: C5.2, IC6.2 (VSS); also elsewhere on the board
GPIO0: Q2.6 (C); also elsewhere on the board
unnamed: D1.P$1 (1), R1.1
unnamed: D2.P$1 (1), R0.2
unnamed: IC2.8 (VBUS), R10.1, R11.1
unnamed: D3.C, F1.1, Q1.2 (S)
unnamed: IC2.9 (#RST), R12.1
PROG: IC4.5 (PROG), R3.1
RESET: Q2.3 (C); also elsewhere on the board
RTS: IC2.19 (RTS), Q2.2 (B), Q2.4 (E)
RXD: IC2.21 (TXD); also elsewhere on the board
STAT: D2.P$2 (2), IC4.1 (STAT)
TXD: IC2.20 (RXD); also elsewhere on the board
VBAT: C3.1, IC4.3 (VBAT), J4.2, Q1.3 (D); also elsewhere on the board
VBUS: C0.2, C7.2, D3.A, IC8.1, J3.A4 (VBUS1), J3.A9 (VBUS2), J3.B4 (VBUS3), J3.B9 (VBUS4), Q1.1 (G), R1.2, R2.1, R10.2
VCC: C5.1, IC6.5 (VOUT); also elsewhere on the board
VDD: C4.1, C6.1, IC2.5 (VIO), IC2.6 (VDD), IC2.7 (REGIN), IC5.5 (VOUT), R12.2; also elsewhere on the board
VREG_IN: C1.1, C2.1, F1.2, IC4.4 (VDD), IC5.1 (VIN), IC5.3 (CE), IC6.1 (VIN), IC6.3 (CE), R0.1

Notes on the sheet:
USB TO SERIAL CONVERTER
10K = 100mA
4.7K = 300mA
2.0K = 500mA
VBATT or VIN < 6.0V Max
POWER
info@ohmic.net
USB

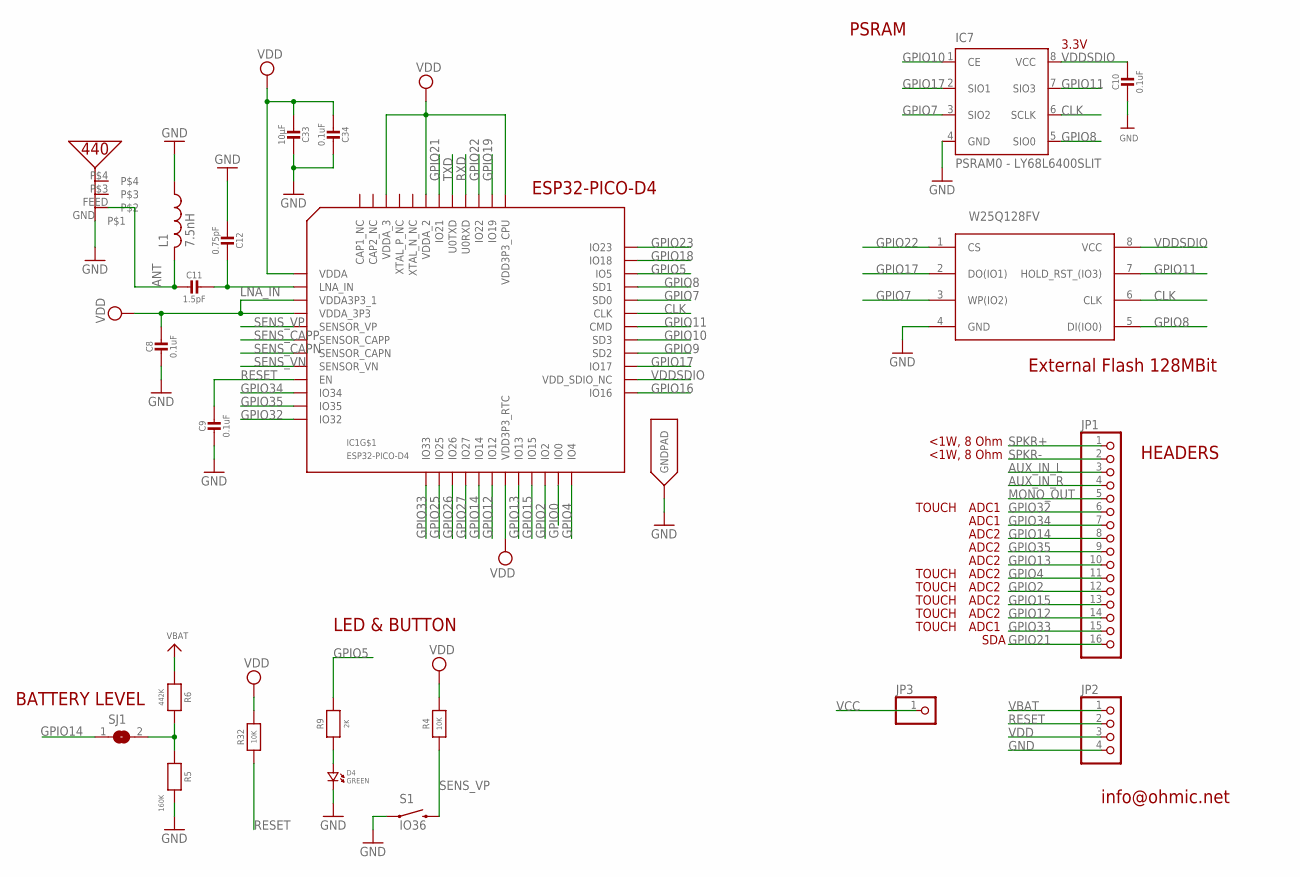
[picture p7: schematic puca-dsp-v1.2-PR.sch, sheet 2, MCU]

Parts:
C8, C9, C10, C34: 0.1uF; _0402MP
C11: 1.5pF; _0402MP
C12: 0.75pF; _0402MP
C33: 10µF; _0603MP
D4: GREEN; 0402.LED
IC1: ESP32-PICO-D4; PICO-D4-QFN48
IC7: PSRAM0 - LY68L6400SLIT; SOP8
IC12: PRO-OB-440
JP1: HEADER-1X16ROUND; 1X16_ROUND
JP2: HEADER-1X4ROUND; 1X04_ROUND
JP3: HEADER-1X1ROUND; 1X01_ROUND
L1: 7.5nH; RESC0402_N
R4, R32: 10K; _0402MP
R5: 160K; _0402MP
R6: 442K; _0402MP
R9: 2K; _0402MP
S1: IO36; TACTILE_SWITCH_SMD_4.6X2.8MM
SJ1: SOLDERJUMPER; SOLDERJUMPER_ARROW_NOPASTE
U$1: W25Q128FV; SOIC127P790X216-8N

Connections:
ANT: C11.2, IC12.FEED, L1.2
AUX_IN_L: JP1.3; also elsewhere on the board
AUX_IN_R: JP1.4; also elsewhere on the board
CLK: IC1.31 (CLK), IC7.6 (SCLK), U$1.6 (CLK)
GND: C8.2, C9.2, C10.2, C12.2, C33.1, C34.1, D4.P$2 (2), IC1.EXP (GNDPAD), IC7.4 (GND), IC12.GND, JP2.4, L1.1, R5.2, S1.1, S1.2 (1), U$1.4 (GND); also elsewhere on the board
GPIO0: IC1.23 (IO0); also elsewhere on the board
GPIO2: IC1.22 (IO2), JP1.12
GPIO4: IC1.24 (IO4), JP1.11
GPIO5: IC1.34 (IO5), R9.2
GPIO7: IC1.32 (SD0), IC7.3 (SIO2), U$1.3 (WP(IO2))
GPIO8: IC1.33 (SD1), IC7.5 (SIO0), U$1.5 (DI(IO0))
GPIO9: IC1.28 (SD2)
GPIO10: IC1.29 (SD3), IC7.1 (CE)
GPIO11: IC1.30 (CMD), IC7.7 (SIO3), U$1.7 (HOLD_RST_(IO3))
GPIO12: IC1.18 (IO12), JP1.14
GPIO13: IC1.20 (IO13), JP1.10
GPIO14: IC1.17 (IO14), JP1.8, SJ1.1
GPIO15: IC1.21 (IO15), JP1.13
GPIO16: IC1.25 (IO16)
GPIO17: IC1.27 (IO17), IC7.2 (SIO1), U$1.2 (DO(IO1))
GPIO18: IC1.35 (IO18); also elsewhere on the board
GPIO19: IC1.38 (IO19); also elsewhere on the board
GPIO21: IC1.42 (IO21), JP1.16
GPIO22: IC1.39 (IO22), U$1.1 (CS)
GPIO23: IC1.36 (IO23); also elsewhere on the board
GPIO25: IC1.14 (IO25); also elsewhere on the board
GPIO26: IC1.15 (IO26); also elsewhere on the board
GPIO27: IC1.16 (IO27); also elsewhere on the board
GPIO32: IC1.12 (IO32), JP1.6
GPIO33: IC1.13 (IO33), JP1.15
GPIO34: IC1.10 (IO34), JP1.7
GPIO35: IC1.11 (IO35), JP1.9
LNA_IN: C11.1, C12.1, IC1.2 (LNA_IN)
MONO_OUT: JP1.5; also elsewhere on the board
unnamed: R5.1, R6.2, SJ1.2
unnamed: D4.P$1 (1), R9.1
RESET: C9.1, IC1.9 (EN), JP2.2, R32.1; also elsewhere on the board
RXD: IC1.40 (U0RXD); also elsewhere on the board
SENS_CAPN: IC1.7 (SENSOR_CAPN)
SENS_CAPP: IC1.6 (SENSOR_CAPP)
SENS_VN: IC1.8 (SENSOR_VN)
SENS_VP: IC1.5 (SENSOR_VP), R4.1, S1.3 (2), S1.4 (2)
SPKR+: JP1.1; also elsewhere on the board
SPKR-: JP1.2; also elsewhere on the board
TXD: IC1.41 (U0TXD); also elsewhere on the board
VBAT: JP2.1, R6.1; also elsewhere on the board
VCC: JP3.1; also elsewhere on the board
VDD: C8.1, C33.2, C34.2, IC1.1 (VDDA), IC1.3 (VDDA3P3_1), IC1.4 (VDDA_3P3), IC1.19 (VDD3P3_RTC), IC1.37 (VDD3P3_CPU), IC1.43 (VDDA_2), IC1.46 (VDDA_3), JP2.3, R4.2, R32.2; also elsewhere on the board
VDDSDIO: C10.1, IC1.26 (VDD_SDIO_NC), IC7.8 (VCC), U$1.8 (VCC)

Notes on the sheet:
ESP32-PICO-D4
PSRAM
3.3V
External Flash 128MBit
LED & BUTTON
HEADERS
ADC1
<1W, 8 Ohm
ADC2
SDA
TOUCH
info@ohmic.net
BATTERY LEVEL

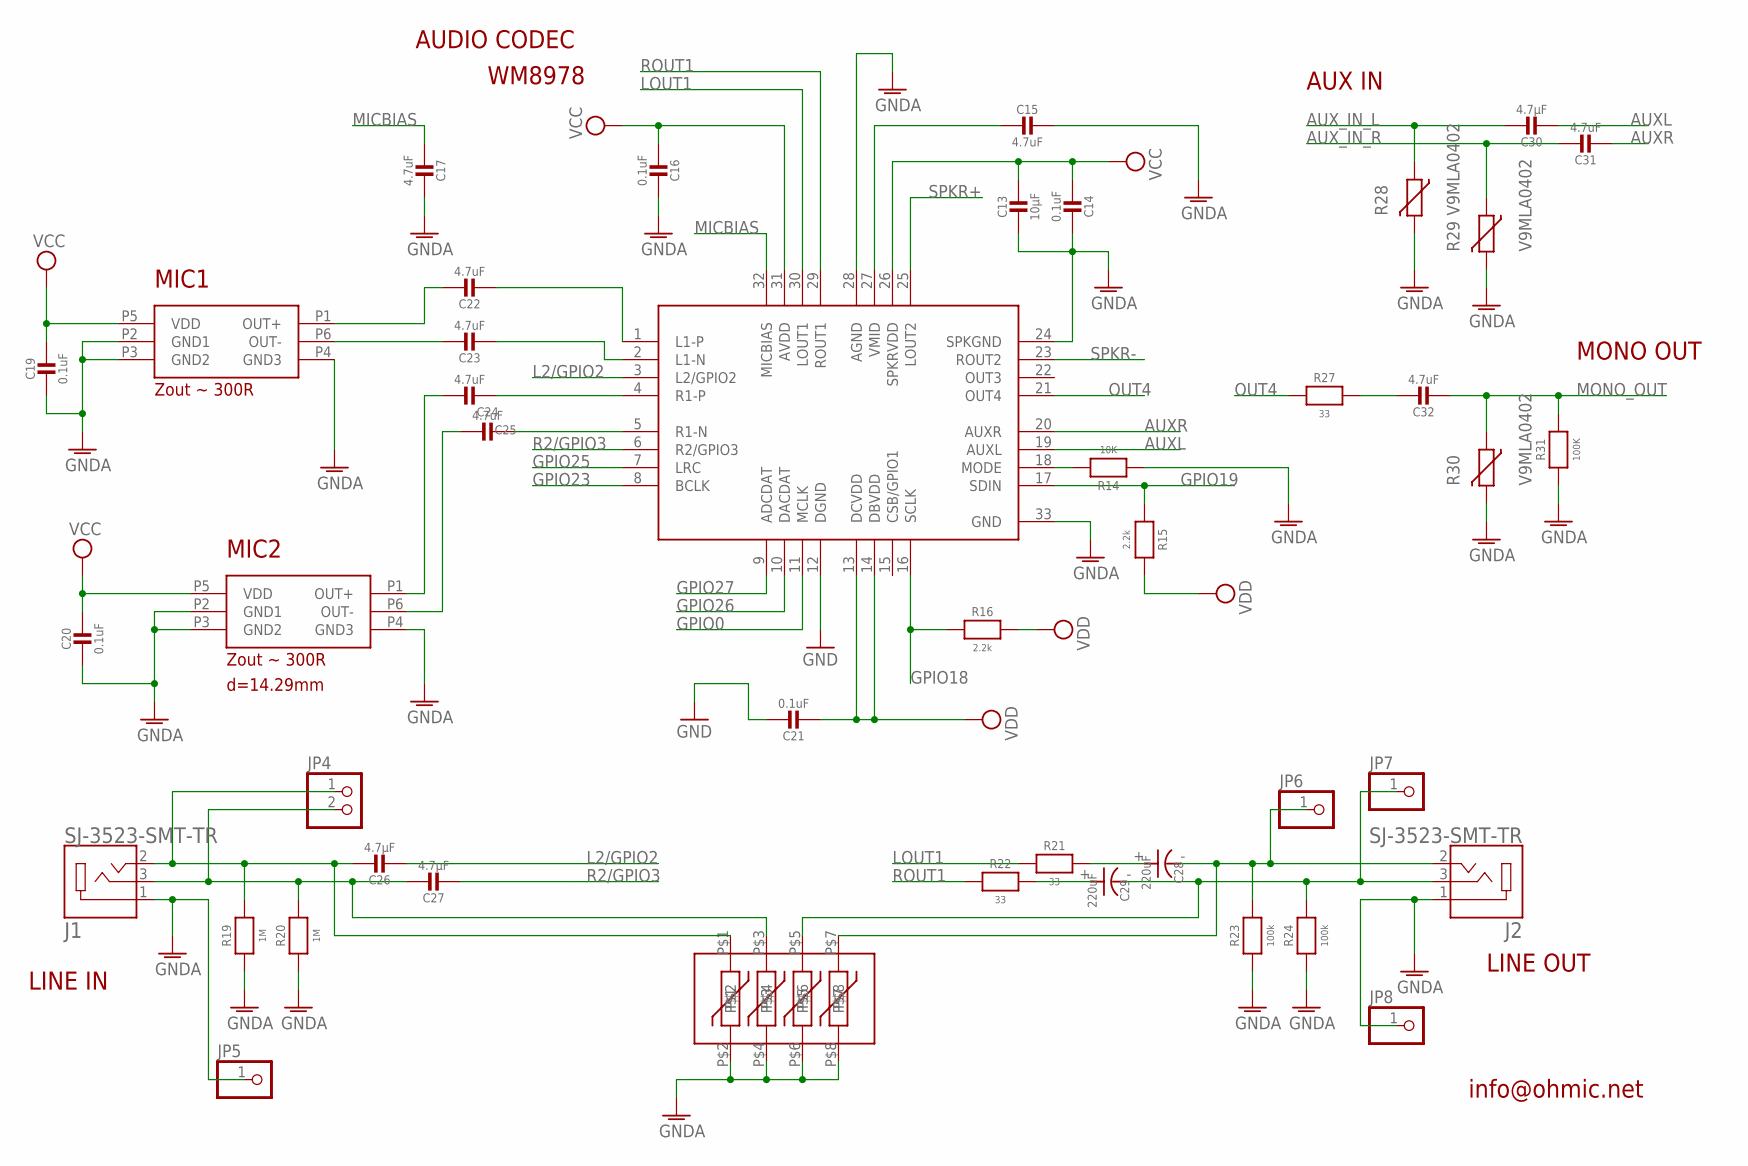
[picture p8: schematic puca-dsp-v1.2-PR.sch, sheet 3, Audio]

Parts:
C13: 10µF; _0603MP
C14, C16, C19, C20, C21: 0.1uF; _0402MP
C15, C17: 4.7uF; _0402MP
C22, C23, C24, C25, C31, C32: 4.7uF; _0805MP
C26, C27, C30: 4.7µF; _0805MP
C28, C29: 220uF; 3528
IC3: WM8978; QFN50P500X500X80-33N
IC9, IC10: SPM0687LR5H-1
IC11: V18MLN41206WT
J1, J2: SJ-3523-SMT-TR; CUI_SJ-3523-SMT-TR
JP4: HEADER-1X2ROUND; 1X02_ROUND
JP5, JP6, JP7, JP8: HEADER-1X1ROUND; 1X01_ROUND
R14: 10K; _0402MP
R15, R16: 2.2k; _0402MP
R19, R20: 1M; _0402MP
R21, R22, R27: 33; _0402MP
R23, R24: 100k; _0402MP
R28, R29, R30: V9MLA0402; CT/CN0402
R31: 100K; _0402MP

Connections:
AUXL: C30.2, IC3.19 (AUXL)
AUXR: C31.2, IC3.20 (AUXR)
AUX_IN_L: C30.1, R28.1; also elsewhere on the board
AUX_IN_R: C31.1, R29.1; also elsewhere on the board
GND: C21.1, IC3.12 (DGND); also elsewhere on the board
GNDA: C13.2, C14.1, C15.1, C16.1, C17.1, C19.2, C20.2, IC3.24 (SPKGND), IC3.28 (AGND), IC3.33 (GND), IC9.P2 (GND1), IC9.P3 (GND2), IC9.P4 (GND3), IC10.P2 (GND1), IC10.P3 (GND2), IC10.P4 (GND3), IC11.P$2, IC11.P$4, IC11.P$6, IC11.P$8, J1.1, J2.1, JP5.1, JP8.1, R14.1, R19.1, R20.1, R23.1, R24.1, R28.2, R29.2, R30.2, R31.1; also elsewhere on the board
GPIO0: IC3.11 (MCLK); also elsewhere on the board
GPIO18: IC3.16 (SCLK), R16.1; also elsewhere on the board
GPIO19: IC3.17 (SDIN), R15.1; also elsewhere on the board
GPIO23: IC3.8 (BCLK); also elsewhere on the board
GPIO25: IC3.7 (LRC); also elsewhere on the board
GPIO26: IC3.10 (DACDAT); also elsewhere on the board
GPIO27: IC3.9 (ADCDAT); also elsewhere on the board
L1_N: C23.2, IC3.2 (L1-N)
L1_P: C22.2, IC3.1 (L1-P)
L2/GPIO2: C26.2, IC3.3 (L2/GPIO2)
LINE_IN_L: C26.1, IC11.P$1, J1.2, JP4.1, R19.2
LINE_IN_R: C27.1, IC11.P$3, J1.3, JP4.2, R20.2
LINE_OUT_L: C28.- (1), IC11.P$7, J2.2, JP6.1, R23.2
LINE_OUT_R: C29.- (1), IC11.P$5, J2.3, JP7.1, R24.2
LOUT1: IC3.30 (LOUT1), R21.1
L_N: C23.1, IC9.P6 (OUT-)
L_P: C22.1, IC9.P1 (OUT+)
MICBIAS: C17.2, IC3.32 (MICBIAS)
MONO_OUT: C32.2, R30.1, R31.2; also elsewhere on the board
unnamed: C28.+ (2), R21.2
unnamed: C29.+ (2), R22.2
unnamed: IC3.18 (MODE), R14.2
unnamed: C32.1, R27.2
unnamed: C15.2, IC3.27 (VMID)
OUT4: IC3.21 (OUT4), R27.1
R1_N: C25.2, IC3.5 (R1-N)
R1_P: C24.2, IC3.4 (R1-P)
R2/GPIO3: C27.2, IC3.6 (R2/GPIO3)
ROUT1: IC3.29 (ROUT1), R22.1
R_N: C25.1, IC10.P6 (OUT-)
R_P: C24.1, IC10.P1 (OUT+)
SPKR+: IC3.25 (LOUT2); also elsewhere on the board
SPKR-: IC3.23 (ROUT2); also elsewhere on the board
VCC: C13.1, C14.2, C16.2, C19.1, C20.1, IC3.26 (SPKRVDD), IC3.31 (AVDD), IC9.P5 (VDD), IC10.P5 (VDD); also elsewhere on the board
VDD: C21.2, IC3.13 (DCVDD), IC3.14 (DBVDD), R15.2, R16.2; also elsewhere on the board

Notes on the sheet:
AUDIO CODEC
MIC1
MIC2
Zout ~ 300R
d=14.29mm
WM8978
LINE IN
LINE OUT
AUX IN
MONO OUT
info@ohmic.net

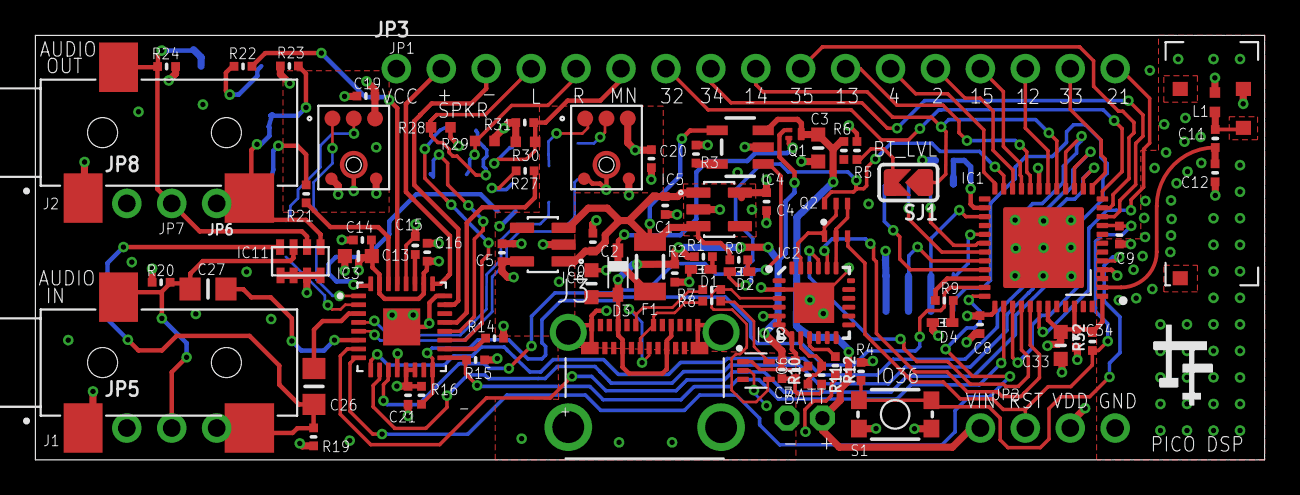
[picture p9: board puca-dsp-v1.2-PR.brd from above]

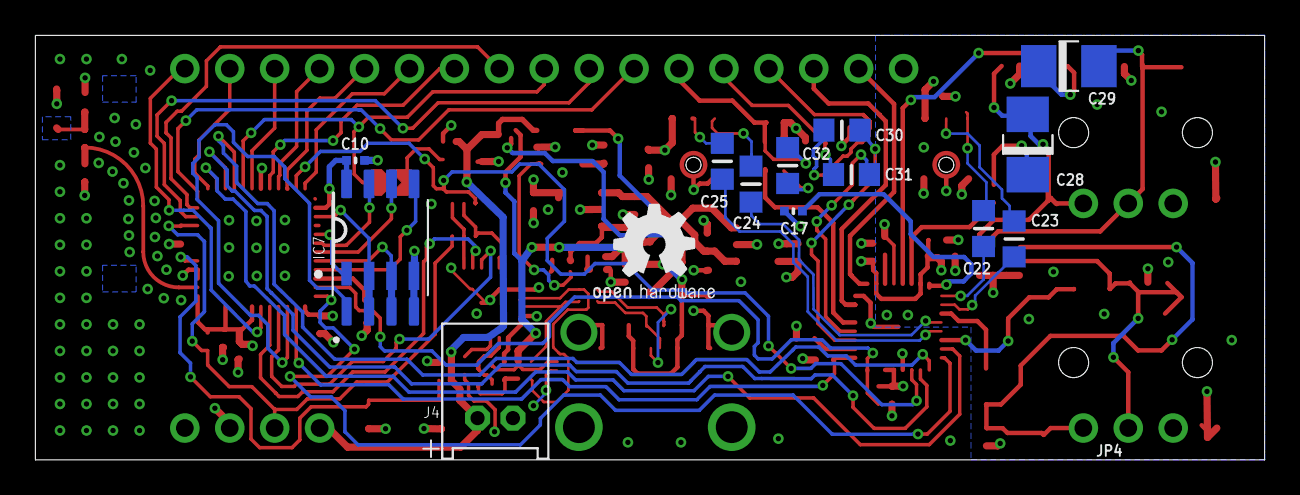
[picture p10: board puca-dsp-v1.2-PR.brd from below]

Board: 4 copper layers, 69.5 x 24.0 mm, 98 parts (16 on the bottom side), 85 nets.

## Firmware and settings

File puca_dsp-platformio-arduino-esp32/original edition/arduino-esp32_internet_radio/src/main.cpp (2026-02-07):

// ESP32 internet radio example for PUCA_DSP development board Original Edition with 4MB Flash & PSRAM Enabled
// Press Button (I036) to change stations

#include "Arduino.h"
#include "WiFi.h"
#include "Audio.h"
#include "WM8978.h"
#include "esp_sleep.h"
#include "driver/periph_ctrl.h"
#include "driver/gpio.h"
#include "freertos/FreeRTOS.h"
#include "freertos/task.h"
#include "freertos/queue.h"
#include "esp_log.h"
 
// Define 12S pins
#define I2S_BCLK       23  // Bit clock  
#define I2S_LRC        25  // Left Right / WS Clock
#define I2S_DOUT       26  
#define I2S_DIN        27

// Define WM8978 MCLK gpio number */
#define I2S_MCLKPIN     0

#if !(USING_DEFAULT_ARDUINO_LOOP_STACK_SIZE)
    uint16_t USER_CONFIG_ARDUINO_LOOP_STACK_SIZE = 16384;
#endif

Audio audio(I2S_BCLK, I2S_LRC, I2S_DOUT);  // create an instance of audio class 
WM8978 wm8978;   // create an instance of audio codec setup. The default Sample Rate for the DAC and ADC is 48kHz
 
String ssid =     "";   // Enter WiFi Network settings here
String password = "";

#define uS_TO_S_FACTOR 1000000 // Conversion factor uS to seconds
#define TIME_TO_SLEEP 2 // time in seconds to sleep for 
#define Button      36

static RTC_NOINIT_ATTR int station_select;   // variable to store in RTC 
portMUX_TYPE mux = portMUX_INITIALIZER_UNLOCKED;
TaskHandle_t complexHandlerTask;   // task handle for the sleep task 

void RTC_variable()       // keeps state of a variable after a software or deep sleep reset 
{ 
    esp_reset_reason_t reason = esp_reset_reason();
    if ((reason != ESP_RST_SW) && (reason != ESP_RST_DEEPSLEEP)) {  
	station_select = 0; }
    station_select++;
    //printf("station_select: %d\n",station_select);
    if (station_select > 3) {
        station_select = 0;
    }
}

void change_station (void) {     // add new stations or change stations here

    switch(station_select) {
        case 0: 
        audio.connecttohost("http://worldwidefm.out.airtime.pro:8000/worldwidefm_a"); // Worldwide FM
        break; 
        case 1: 
        audio.connecttohost("http://listen2.ntslive.co.uk/listen.pls"); // NTS
        break;
        case 2: 
        audio.connecttohost("http://dublindigitalradio.out.airtime.pro:8000/dublindigitalradio_a");  //DDR
        break;  
        //case 3:
        //audio.connecttohost("http://streamer.dgen.net:8000/rinseradio"); // Rinse FM
        //break;
        } 
}

void IRAM_ATTR isr() {  // interrupt function is stored in IRAM, sets a flag to be checked by non interrupt code 
  portENTER_CRITICAL_ISR(&mux);  
    BaseType_t xHigherPriorityTaskWoken = pdFALSE;  // notify complexHandlerTask that the buffer is full
    vTaskNotifyGiveFromISR(complexHandlerTask, &xHigherPriorityTaskWoken);  // notifies the complex task that the ISR has something for it to do
    if (xHigherPriorityTaskWoken) {
      portYIELD_FROM_ISR();
  }
  portEXIT_CRITICAL_ISR(&mux);
}

void complexHandler(void *param) {    // the complex task that doesn't fit in the ISR
  //for (;;) {   
    //uint32_t tcount = ulTaskNotifyTake(pdTRUE, pdMS_TO_TICKS(5000));  // Sleep until the ISR gives us something to do, or for 5 seconds
    ulTaskNotifyTake(pdFALSE, portMAX_DELAY);  // Block indefinitely without using CPU, until there is a notification  
    esp_deep_sleep_start(); 
    vTaskDelete(NULL); // it's a one off task, so it can be deleted once it's finished 
  //}
}

void setup() {

    Serial.begin(115200);

    wm8978.init();  // Audio codec initialisation 
    wm8978.addaCfg(1,1); 
    wm8978.inputCfg(1,0,0);     
    wm8978.outputCfg(1,0); 
    wm8978.sampleRate(0); 
    wm8978.micGain(30);
    wm8978.auxGain(0);
    wm8978.lineinGain(0);
    wm8978.spkVolSet(55);  // speaker volume, range 0-63
    wm8978.hpVolSet(40,40);  // headphones volume, range 0-63
    wm8978.i2sCfg(2,0);  // I2S format MSB, 16Bit 
    wm8978.eq1Set(80,22); // eq 1 
    wm8978.eq2Set(385,6); 
    wm8978.eq5Set(11700,13); // eq5
    wm8978.spkBoost(1); // speaker boost enable

    WiFi.mode(WIFI_STA);
    WiFi.begin(ssid.c_str(), password.c_str());
    while (WiFi.status() != WL_CONNECTED) delay(1500);

    audio.setPinout(23, 25, 26, 27);
    audio.i2s_mclk_pin_select(I2S_MCLKPIN);    
    audio.setSampleRate(48000);   // I2S Sample Rate
    audio.setBitsPerSample(16);
    audio.setChannels(2); 
    audio.setVolume(20);  // range 0-21

    pinMode(Button, INPUT);
    xTaskCreatePinnedToCore(complexHandler, "ISR Handler Task", 8192, NULL, 20, &complexHandlerTask, tskNO_AFFINITY);
    attachInterrupt(digitalPinToInterrupt(Button), isr, FALLING);
    esp_sleep_enable_timer_wakeup(TIME_TO_SLEEP * uS_TO_S_FACTOR);
    RTC_variable();
    vTaskDelay(pdMS_TO_TICKS(30));

    //station_select = 2; 
    change_station(); 
    ESP_LOGI(TAG, "Connected. Starting MP3..."); 
}


void loop()
{
    audio.audiotask();      // audio task 
}
 
// optional
void audio_info(const char *info){
    Serial.print("info        "); Serial.println(info);
}
void audio_id3data(const char *info){  //id3 metadata
    Serial.print("id3data     ");Serial.println(info);
}
// void audio_eof_mp3(const char *info){  //end of file
//     Serial.print("eof_mp3     ");Serial.println(info);
// }
void audio_showstation(const char *info){
    Serial.print("station     ");Serial.println(info);
}
void audio_showstreaminfo(const char *info){
    Serial.print("streaminfo  ");Serial.println(info);
}
void audio_showstreamtitle(const char *info){
    Serial.print("streamtitle ");Serial.println(info);
}
void audio_bitrate(const char *info){
    Serial.print("bitrate     ");Serial.println(info);
}
// void audio_commercial(const char *info){  //duration in sec
//     Serial.print("commercial  ");Serial.println(info);
// }
// void audio_icyurl(const char *info){  //homepage
//     Serial.print("icyurl      ");Serial.println(info);
// }
void audio_lasthost(const char *info){  //stream URL played
    Serial.print("lasthost    ");Serial.println(info);
}
// void audio_eof_speech(const char *info){
//     Serial.print("eof_speech  ");Serial.println(info);
// }

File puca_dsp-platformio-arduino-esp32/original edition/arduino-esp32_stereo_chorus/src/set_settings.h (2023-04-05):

#ifndef SETTINGS_H_
#define SETTINGS_H_
  
  #pragma once
  #include "codec.h"
  #include <Arduino.h>
  #include "driver/i2s.h"

  #define SAMPLE_RATE     (48000)
  #define BITS_PER_SAMPLE (16)
  #define CHANNEL_COUNT 2

  //ESP32 PUCA PIN ASSIGNMENTS
  //~~~~~~~~~~~~~~~~~~~~~~~~~~~

  #define POT1 33          
  #define POT2 34         
  #define POT3 32
  #define POT4 32
  
  #define LED1 4
  #define LED2 2
  
  #define KEY1 13  //TR1
  #define KEY2 14  //TR2
  #define KEY3 15  //TOUCH
  #define KEY4 36  
  #define KEY_BOARD 37

  #define TOUCH_THRESHOLD 30

//ESP32-Codec PIN SETUP
#define I2S_NUM			(0)
#define IS2_MCLK_PIN (0)
#define I2S_BCLK	  (23)
#define I2S_LRC     (25)
#define I2S_DIN     (27)
#define I2S_DOUT    (26)

#define Codec_SDA	     19  //SDA
#define Codec_SCK		   18   //SCL
#define I2C_MASTER_SCL_IO 18
#define I2C_MASTER_SDA_IO 19
#define Codec_ADDR	  0x1A  //WM8978
#define WM8978_ADDR   0X1A    //WM8978
#define I2C_MASTER_NUM 1 /*!< I2C port number for master dev */
#define I2C_MASTER_FREQ_HZ 100000
#define I2C_MASTER_TX_BUF_DISABLE 0
#define I2C_MASTER_RX_BUF_DISABLE 0

//audio processing frame length in samples (L+R) 64 samples (32R+32L) 256 Bytes
//Used as size of i2s input and output buffers
#define FRAMELENGTH    256
//audio processing priority
#define AUDIO_PROCESS_PRIORITY  10

//SRAM used for DMA = DMABUFFERLENGTH * DMABUFFERCOUNT * BITS_PER_SAMPLE/8 * CHANNEL_COUNT
//Lower number for low latency, Higher number for more signal processing time
//Must be value between 8 and 1024 in bytes
#define DMABUFFERLENGTH 64

//number of above DMA Buffers of DMABUFFERLENGTH
#define DMABUFFERCOUNT  4

  // processor timing variables for system monitor, also included in task.cpp
  extern unsigned int runningTicks;
  extern unsigned int usedticks;
  extern unsigned int availableticks;
  extern unsigned int availableticks_start;
  extern unsigned int availableticks_end;
  extern unsigned int usedticks_start;
  extern unsigned int usedticks_end;
  extern unsigned int processedframe;
  extern unsigned int audiofps;

 void I2S_init(void);

#endif

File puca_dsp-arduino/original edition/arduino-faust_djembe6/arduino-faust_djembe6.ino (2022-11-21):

// faust djembe example for PUCA_DSP development board 
// Choose board ESP32 Dev Module, Flash Size 4MB, Partition scheme default 4MB with spiffs, PSRAM Enabled 
// Attach a potentiometers between GND, 3.3V and IO32, I033 and IO34 to change the DSP parameters
// DSP task and ADC task running on Core 0
// For Strawberry Edition PICO_DSP with 16MB Flash, choose a board with 16MB Flash, a 16MB Partition scheme with spiffs and PSRAM Disabled

#include "freertos/FreeRTOS.h"
#include "freertos/task.h"
#include "WM8978.h"
#include "djembe6.h"
#include <stdio.h>
#include <stdlib.h>
#include <math.h>
#include "freertos/FreeRTOSConfig.h"
#include "freertos/semphr.h"
#include "driver/gpio.h"
#include "driver/adc.h"
#include "driver/timer.h"
#include "esp_timer.h"
#include "esp_attr.h"
#include "esp_intr_alloc.h"
#include "esp_adc_cal.h"
#include "soc/soc.h"
#include "soc/timer_group_struct.h" 
#include "soc/timer_group_reg.h"

#define DEFAULT_VREF    1093
#define NO_OF_SAMPLES   512 

TaskHandle_t adc_read_task;  
TaskHandle_t update_parameters_task;

SemaphoreHandle_t xSemaphore = NULL;  // binary semaphores for parameters
SemaphoreHandle_t ySemaphore = NULL;  
SemaphoreHandle_t zSemaphore = NULL;

WM8978 wm8978;
djembe6* DSP = new djembe6(32000, 32);

float adc_read_1, adc_read_2, adc_read_3, map_output, map_input, freq, stPos, Sharp  = 0;

void adc_config()
{   
REG_WRITE(0x3FF48800,461088); // write to register for ADC1 to change ADC clk div
vTaskDelay(pdMS_TO_TICKS(10));
esp_adc_cal_characteristics_t *adc_chars = (esp_adc_cal_characteristics_t *)calloc(1, sizeof(esp_adc_cal_characteristics_t));  
esp_adc_cal_characterize(ADC_UNIT_1, ADC_ATTEN_11db, ADC_WIDTH_BIT_12, DEFAULT_VREF, adc_chars);         
}

float map_adc (float map_input, float output_start, float output_end) {         // function to map adc range, gets called from send_value_task 
    float input_start = 0;
    float input_end = 4095; 
    
    while(1) {
    float slope = 1.0 * (output_end - output_start) / (input_end - input_start);  
    map_output = output_start + slope * (map_input - input_start);  //  map_output = output_start + round (slope * (map_input - input_start));
    return map_output; 
    } 
}

void read_adc( void * pvParameters )     // read adc and map values 
{  
   xSemaphore = xSemaphoreCreateBinary();
   ySemaphore = xSemaphoreCreateBinary();
   zSemaphore = xSemaphoreCreateBinary(); 

   for (;;) { 
 
     for (uint32_t i = 0; i < NO_OF_SAMPLES; i++) {  
         adc_read_1 = adc1_get_raw(ADC1_CHANNEL_4); //IO32
         adc_read_2 = adc1_get_raw(ADC1_CHANNEL_5); //IO33 
         adc_read_3 = adc1_get_raw(ADC1_CHANNEL_6); //IO34 
         vTaskDelay(pdMS_TO_TICKS(30));
         stPos = map_adc(adc_read_1, 0, 1);  
         Sharp = map_adc(adc_read_3, 0, 1); 
         freq = map_adc(adc_read_2, 50, 800);
         
     }
   }

    TIMERG0.wdt_wprotect=TIMG_WDT_WKEY_VALUE;
    TIMERG0.wdt_feed=1;
    TIMERG0.wdt_wprotect=0;
    //if( xSemaphore != NULL && ySemaphore != NULL)
    if( xSemaphore != NULL && ySemaphore != NULL && zSemaphore != NULL)
   {
   }
}

void update_parameters (void *pvParameters)   // task that takes the semaphores and updates the dsp parameters
{
      for (;;) {
              for (uint32_t i = 0; i < NO_OF_SAMPLES; i++) {

              DSP->setParamValue("freq", freq);
              DSP->setParamValue("stPos", stPos);
              DSP->setParamValue("Sharp", Sharp); 
              vTaskDelay(pdMS_TO_TICKS(50));

              TIMERG0.wdt_wprotect=TIMG_WDT_WKEY_VALUE;
              TIMERG0.wdt_feed=1;
              TIMERG0.wdt_wprotect=0;
            } 
        }
    //if( xSemaphore != NULL && ySemaphore != NULL)
    if( xSemaphore != NULL && ySemaphore != NULL && zSemaphore != NULL)
    {
        //if( xSemaphoreTake( xSemaphore, portMAX_DELAY ) && xSemaphoreTake( ySemaphore, portMAX_DELAY ))
        if( xSemaphoreTake( xSemaphore, portMAX_DELAY ) && xSemaphoreTake( ySemaphore, portMAX_DELAY ) && xSemaphoreTake( zSemaphore, portMAX_DELAY))    
        // wait forever without blocking
        {
        //vTaskDelay(pdMS_TO_TICKS(10)); 
        TIMERG0.wdt_wprotect=TIMG_WDT_WKEY_VALUE;
        TIMERG0.wdt_feed=1;
        TIMERG0.wdt_wprotect=0;
    
        xSemaphoreGive( xSemaphore );
        xSemaphoreGive( ySemaphore ); 
        xSemaphoreGive( zSemaphore );  
        }
        else
        {
        }
    }
}

void setup() {

  Serial.begin(115200);

  wm8978.init();
  wm8978.addaCfg(1,1); 
  wm8978.inputCfg(0,0,0);     
  wm8978.outputCfg(1,0); 
  wm8978.sampleRate(1);
  wm8978.micGain(30);
  wm8978.auxGain(0);
  wm8978.lineinGain(0);
  wm8978.spkVolSet(50);
  wm8978.hpVolSet(50,50);
  wm8978.i2sCfg(2,0);  //format 12S, length 16bit
  
  vTaskDelay(pdMS_TO_TICKS(100));
  adc_config(); 
  //xTaskCreatePinnedToCore(read_adc, "adc_read_task", 2048, NULL, 5, &adc_read_task, 0);  
  //xTaskCreatePinnedToCore(update_parameters, "update_parameters_task", 2048, NULL, 6, &update_parameters_task, 0); 
 
  DSP->start(); 
  vTaskDelay(pdMS_TO_TICKS(100));
}

void loop() {
     freq = rand()%(700-50 + 1) + 50; 
     vTaskDelay(pdMS_TO_TICKS(50));
     Serial.println("Freq = "); 
     Serial.print(freq); 
}

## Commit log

2021-08-03 Add Arduino examples
2021-08-06 Add v1.0 schematic
2021-08-06 Update v1.0 schematic
2021-08-09 Schematic v1.0 updated
2021-08-10 Add arduino-esp32 examples
2021-08-13 Add i2c clk flag to config
2021-09-09 Add i2c config clock flag
2021-09-13 Add Arduino as ESP-IDF component example
2023-04-14 Add Eagle files
    [puca-dsp-v1.2-PR.brd, puca-dsp-v1.2-PR.sch]
2024-03-26 Update schematic pdf file
2024-07-31 Add eurorack v0.5 schematic

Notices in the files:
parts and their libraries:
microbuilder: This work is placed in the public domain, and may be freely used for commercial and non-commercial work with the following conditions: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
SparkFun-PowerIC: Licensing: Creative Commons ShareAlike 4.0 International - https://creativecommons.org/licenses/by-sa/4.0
